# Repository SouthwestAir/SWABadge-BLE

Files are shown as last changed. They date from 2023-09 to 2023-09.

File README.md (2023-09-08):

# 📛 SWABadge

 






#### Custom BLE circuit, 3d printed case and button, and sample iOS code

## 💡 Concept

Creation of a wearable Bluetooth "badge" to receive urgent notifications, and respond immediately via a tap.

## 📜 Background

During our recent prototype testing in the lobby, we rolled out a feature enabling our Customer Service Agents (CSAs) to access tools via their mobile devices. We noticed that, especially during interactions with passengers, their iPads would accumulate numerous notifications.

We designed and built a Bluetooth button that vibrates for essential notifications, such as a passenger requiring assistance. With a simple press, CSAs can acknowledge and signal their response, effectively communicating, "Yes, I'm on it!" Leveraging our 3D printing capabilities and existing IoT expertise, we crafted a BLE circuit for this solution.

Our four-step build process was:

1. Build the BLE circuit
2. Integrate into the [chat code](https://github.com/SouthwestAir/SWAChat)
3. 3d print a case
4. Assemble and test!

### Integration into the chat code

We used the chat code from our previous open source project [`SWAChat`](https://github.com/SouthwestAir/SWAChat):

- [https://github.com/SouthwestAir/SWAChat](https://github.com/SouthwestAir/SWAChat)

After following the instructions (setting up and connecting to a Firebase instance) we will have a basis for adding our Bluetooth connectivity.

The first thing we need to do is modify the Info.plist to ask permission to use Bluetooth.

You can do this one of two ways:

a) In your Info.plist, add the row for "Privacy - Bluetooth Always Usage Description", and add a string that is something like "This app requires the use of Bluetooth to connect to our cool comm badge."

b) If you prefer to modify the plist via the "Open as source code" method, add this inside the parent `<dict></dict>` fields:

```
	<key>NSBluetoothAlwaysUsageDescription</key>
	<string>This app requires the use of Bluetooth to connect to our cool comm badge.</string>
```

Then you can copy or add a new file "NewToothManager.swift" found in this repository (in the `02-Chat-code` folder). That file connects and manages the comm device.

(This was built with the assumption that only one comm device will be used at a time, to make this simpler to implement. There are only two basic features for this device, although that could be enhanced as well.)

To integrate this feature into a ViewController, there are two features to implement.

The first is to notify a user when something requires their attention. The badge will vibrate when this message is successfully sent:

```
  // BLE Message sent to SWABadge device if available
  NewToothManager.shared.sendBuzz(msg: "notify user")
```

*<span style="color:red">(If using the ChatDemo, this can be added to the `reloadCurrentChatMessages` method of the `ChatViewController-Messages.swift` file, within the `if channel == currentChatRoom` code block.</span>)*

The second feature is to accept a response from the wearer. We do this by subscribing to an in-app notification, via the NotificationCenter singleton:

```
  NotificationCenter.default.addObserver(
    self,
    selector: #selector(self.swaBadgeTapped(_:)),
    name: Notification.Name.swaBadgeTapped,
    object: nil
  )
```

And we will need to do something with that message, like the following:

```
  @objc func swaBadgeTapped(_ notification: Notification) {
    // do something when the badge button is tapped

  }
```

*<span style="color:red">(If using the ChatDemo, this can be added to the `ChatViewController-Form.swift` file. Add the notification in `setupForm()`, paste the `swaBadgeTapped` method in the file, and replace the `TODO` with something like `sendMessage(self, message: "On it! (sent via SWABadge)")`.</span>)*

Then build and test, to make sure this feature is working with the circuit.

## 🚀 Future ideas

We had a number of enhancements that we've come up with, using this badge as a base. For example, we were thinking about adding a speaker and microphone to allow the wearer to hear a message (i.e. "help needed at gate C15", respond with their voice, and then use speech-to-text on their phone to submit it as a chat message). This would be complicated by having to send audio via a bytestream through Bluetooth.

## 💻 Contributors

The following members of Technology Innovation contributed to this project:

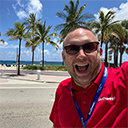
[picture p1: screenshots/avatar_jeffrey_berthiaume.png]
Jeffrey Berthiaume
|  |
| :---: | 
| Jeffrey Berthiaume  |
|  |
|  |
|  |

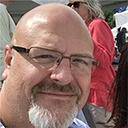
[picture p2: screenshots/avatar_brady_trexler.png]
Brady Trexler
|  |
| :---: | 
| E. Brady Trexler, PhD  |
|  |

## 📖 Citations

Reference to cite if needed:

```
@software {
	title = {SWA Badge},
	author = {Technology Innovation},
	affiliation = {Southwest Airlines},
	url = {https://github.com/SouthwestAir/SWABadge},
	month = {09},
	year = {2023},
	license: {BSD-3-Clause}
	version: {1.0}
}

```

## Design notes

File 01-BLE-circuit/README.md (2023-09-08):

# BLE Circuit

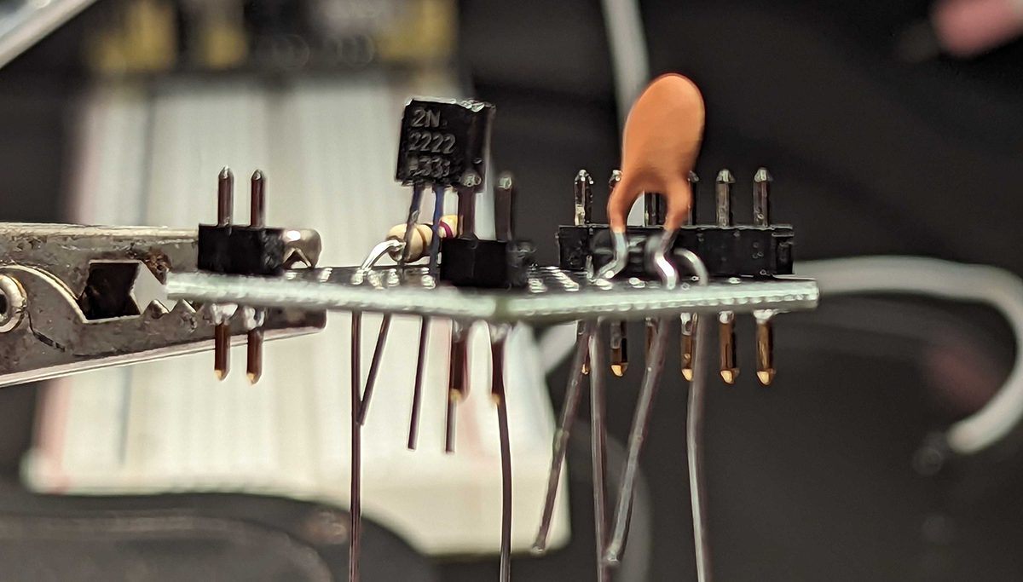
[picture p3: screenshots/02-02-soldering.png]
Soldering parts


The following parts were used to make this circuit:

- [SEEED STUDIO XIAO ESP32C3 WIFI+B](https://www.digikey.com/en/products/detail/seeed-technology-co-ltd/113991054/16652880)
- [VIBRATION ERM MTR 10000 RPM 3V](https://www.digikey.com/en/products/detail/seeed-technology-co-ltd/316040004/5487673)
- [Xiaoyztan 100 Pcs White Light LED Bead Chips DC 3.0-3.2V 280mA 1W Emitting Diodes LED Emitters (White Light)](https://www.amazon.com/gp/product/B07DWR671V/ref=ppx_yo_dt_b_asin_title_o04_s00?ie=UTF8&psc=1)
- [BOJACK 1000 Pcs 25 Values Resistor Kit 1 Ohm-1M Ohm with 5% 1/4W Carbon Film Resistors Assortment](https://www.tindie.com/products/debinix/tiny-1x1-through-hole-prototype-board/)
- [BOJACK 1N4007 Rectifier Diode 1 A 1000 V DO-41 Axial 4007 1 amp 1000 Volt Electronic Silicon Diodes(Pack of 125 Pieces)](https://www.amazon.com/gp/product/B07Q6J9TNW/ref=ppx_yo_dt_b_asin_title_o00_s00?ie=UTF8&psc=1)
- [BOJACK 2N2222 NPN 60V 0.8A 0.5W 250MHZ Power General Purpose Transistors(Pack of 200 Pcs)](https://www.amazon.com/gp/product/B07T61M92G/ref=ppx_yo_dt_b_asin_title_o03_s01?ie=UTF8&psc=1)
- [BOJACK 10 Values 300 Pcs Ceramic Capacitor 0.1 0.15 0.22 0.33 0.47 0.68 1 2.2 4.7 10 uF Multilayer Monolithic Ceramic Capacitor Assortment Kit](https://www.amazon.com/BOJACK-Capacitor-Multilayer-Monolithic-Assortment/dp/B085RDTCCV?th=1)
- [QTETAK 200 Pcs 10 Value Micro Momentary Tactile Push Button Switch Tact Assortment Kit](https://www.amazon.com/gp/product/B07LCBLB8N/ref=ppx_yo_dt_b_asin_title_o09_s00?ie=UTF8&psc=1)
- [Tiny 1”x1” Through Hole Prototype Board -- originally from Amazon, but no longer available](https://www.tindie.com/products/debinix/tiny-1x1-through-hole-prototype-board/)

These are the main steps we followed to construct this circuit:

- Utilize only one side of the ESP32 pins for simplified soldering and assembly.
- Connect pin D7 to the LED, functioning as a digital output. When set to HIGH, the LED will turn on. The SEEED XIAO-ESP32-C3 is capable of supplying the required current for the LED directly from its digital output pins.
- Power the vibration motor using the 3.3-volt output from the ESP32. Control the motor's operation through pin D8, which also serves as a digital output.

For more details:

[Sourcing parts](sourcing_parts.md)

[Constructing the circuit](building_the_circuit.md)

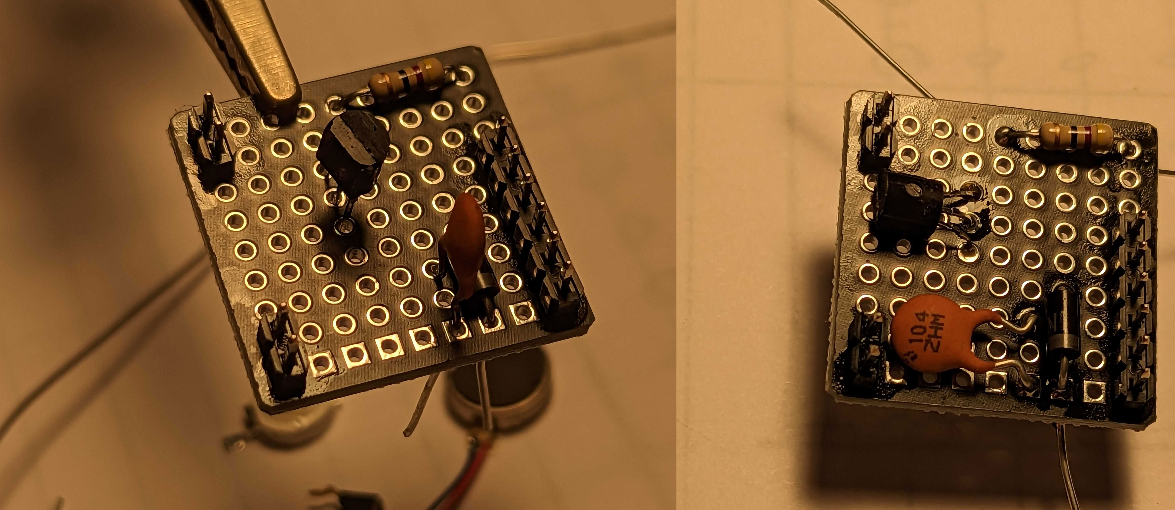
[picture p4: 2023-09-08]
01-BLE-circuit/circuit/circuit02.jpg

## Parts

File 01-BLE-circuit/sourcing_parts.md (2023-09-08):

SEEED STUDIO XIAO ESP32C3 WIFI+B  https://www.digikey.com/en/products/detail/seeed-technology-co-ltd/113991054/16652880

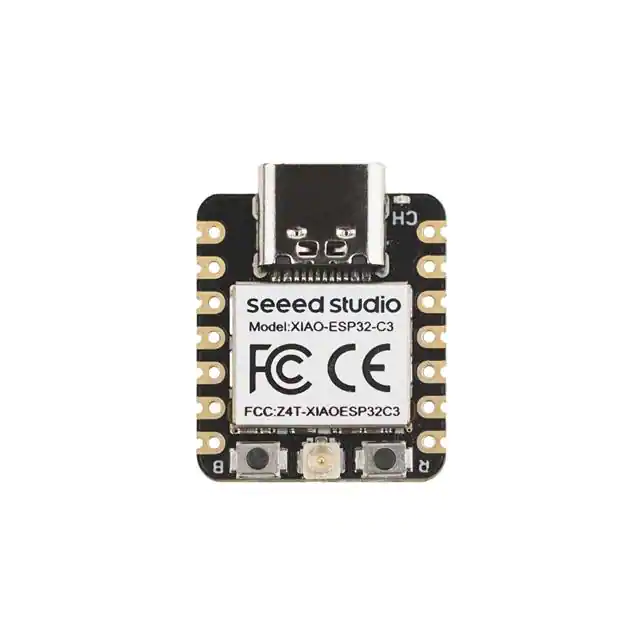
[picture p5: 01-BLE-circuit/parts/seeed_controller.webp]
SEEED STUDIO XIAO ESP32C3 WIFI+B


VIBRATION ERM MTR 10000 RPM 3V
https://www.digikey.com/en/products/detail/seeed-technology-co-ltd/316040004/5487673

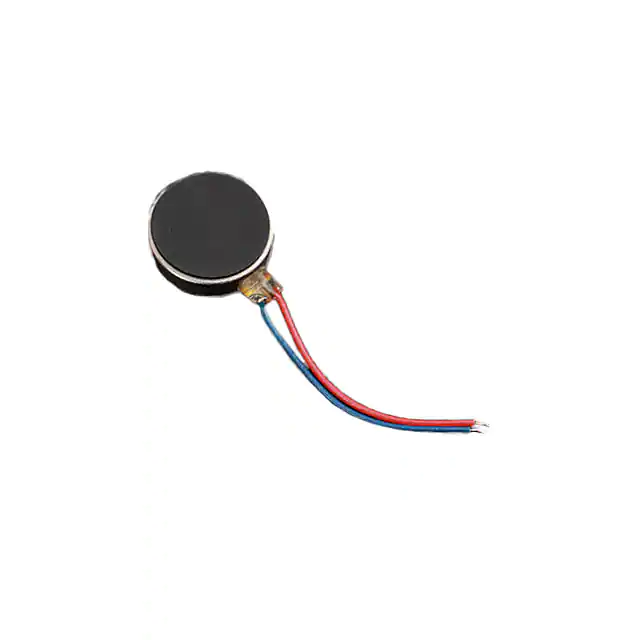
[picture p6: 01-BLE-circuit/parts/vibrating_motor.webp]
VIBRATION ERM MTR 10000 RPM 3V


Xiaoyztan 100 Pcs White Light LED Bead Chips DC 3.0-3.2V 280mA 1W Emitting Diodes LED Emitters (White Light)
https://www.amazon.com/gp/product/B07DWR671V/ref=ppx_yo_dt_b_asin_title_o04_s00?ie=UTF8&psc=1

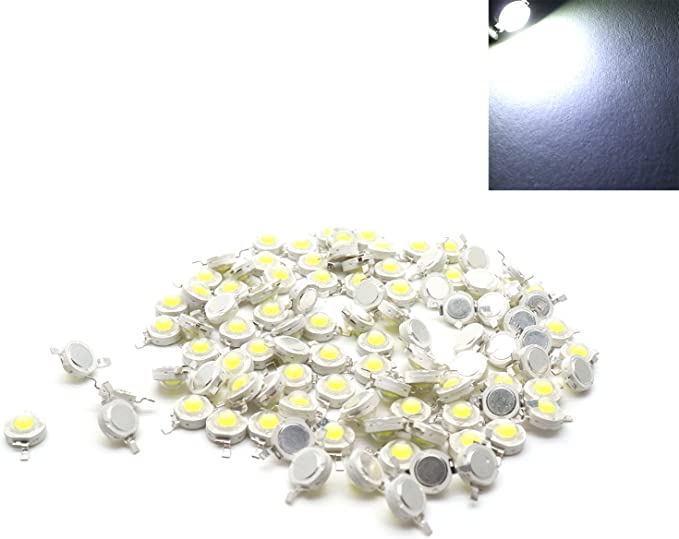
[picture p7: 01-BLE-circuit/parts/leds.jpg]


BOJACK 1000 Pcs 25 Values Resistor Kit 1 Ohm-1M Ohm with 5% 1/4W Carbon Film Resistors Assortment
https://www.tindie.com/products/debinix/tiny-1x1-through-hole-prototype-board/

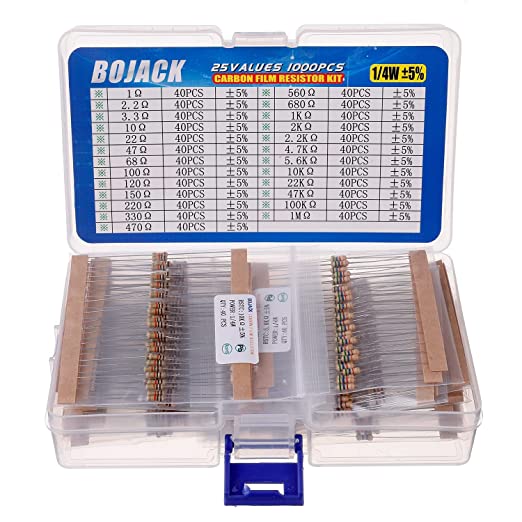
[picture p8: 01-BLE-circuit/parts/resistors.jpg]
BOJACK 1000 Pcs 25 Values Resistor Kit 1 Ohm-1M Ohm with 5% 1/4W Carbon Film Resistors Assortment


BOJACK 1N4007 Rectifier Diode 1 A 1000 V DO-41 Axial 4007 1 amp 1000 Volt Electronic Silicon Diodes(Pack of 125 Pieces)
https://www.amazon.com/gp/product/B07Q6J9TNW/ref=ppx_yo_dt_b_asin_title_o00_s00?ie=UTF8&psc=1

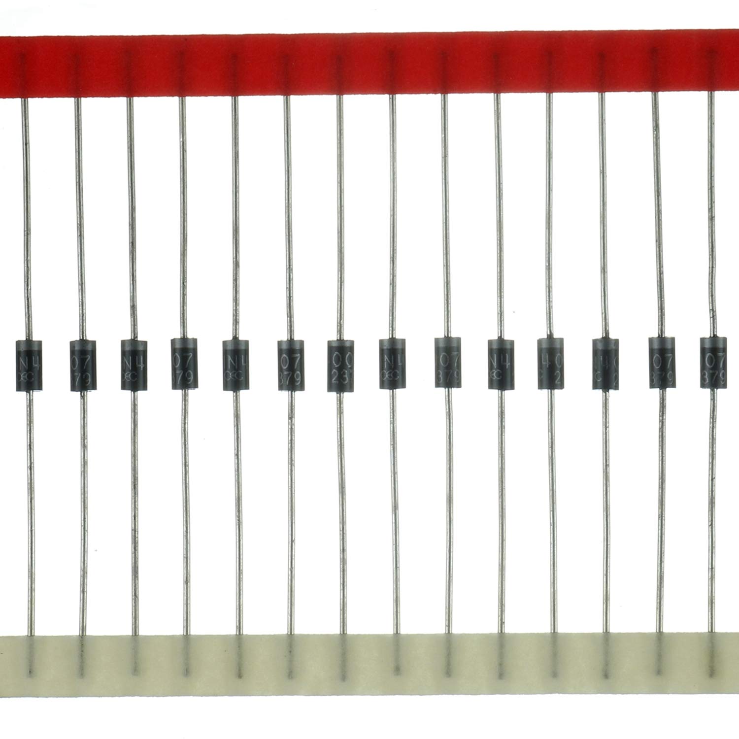
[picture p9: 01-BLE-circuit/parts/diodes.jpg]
BOJACK 1N4007 Rectifier Diode 1 A 1000 V DO-41 Axial 4007 1 amp 1000 Volt Electronic Silicon Diodes(Pack of 125 Pieces)


BOJACK 2N2222 NPN 60V 0.8A 0.5W 250MHZ Power General Purpose Transistors(Pack of 200 Pcs)
https://www.amazon.com/gp/product/B07T61M92G/ref=ppx_yo_dt_b_asin_title_o03_s01?ie=UTF8&psc=1

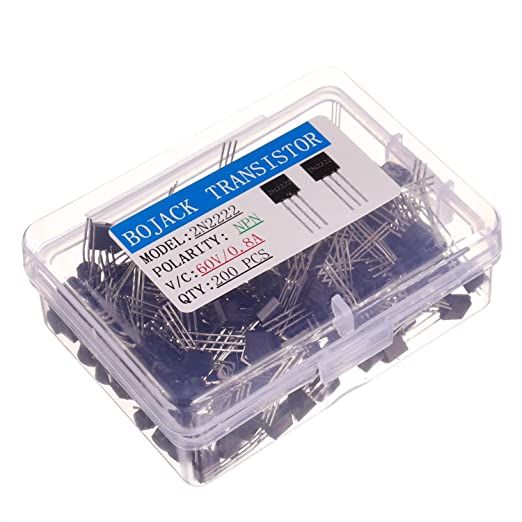
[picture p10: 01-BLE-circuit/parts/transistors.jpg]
BOJACK 2N2222 NPN 60V 0.8A 0.5W 250MHZ Power General Purpose Transistors(Pack of 200 Pcs)


BOJACK 10 Values 300 Pcs Ceramic Capacitor 0.1 0.15 0.22 0.33 0.47 0.68 1 2.2 4.7 10 uF Multilayer Monolithic Ceramic Capacitor Assortment Kit
https://www.amazon.com/BOJACK-Capacitor-Multilayer-Monolithic-Assortment/dp/B085RDTCCV?th=1

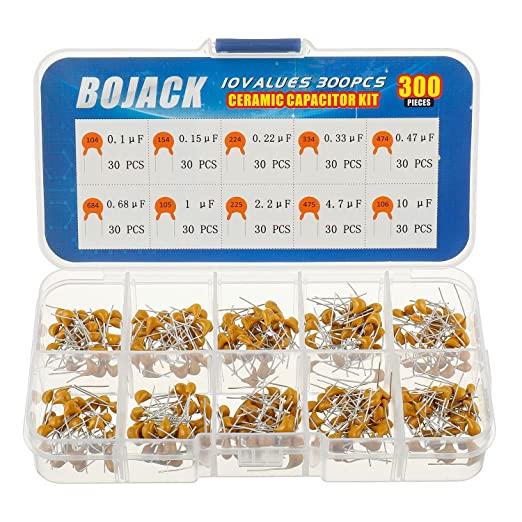
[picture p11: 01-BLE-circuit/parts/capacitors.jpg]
BOJACK 10 Values 300 Pcs Ceramic Capacitor 0.1 0.15 0.22 0.33 0.47 0.68 1 2.2 4.7 10 uF Multilayer Monolithic Ceramic Capacitor Assortment Kit


QTETAK 200 Pcs 10 Value Micro Momentary Tactile Push Button Switch Tact Assortment Kit
https://www.amazon.com/gp/product/B07LCBLB8N/ref=ppx_yo_dt_b_asin_title_o09_s00?ie=UTF8&psc=1

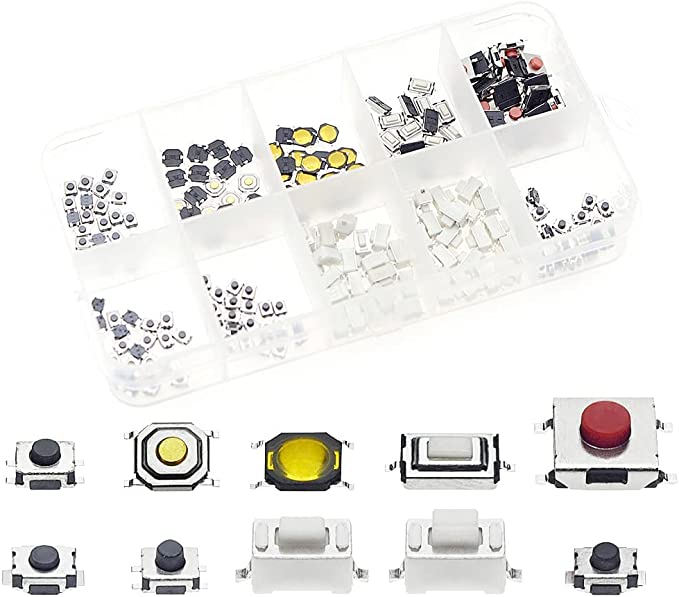
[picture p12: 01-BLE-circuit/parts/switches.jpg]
QTETAK 200 Pcs 10 Value Micro Momentary Tactile Push Button Switch Tact Assortment Kit


Tiny 1”x1” Through Hole Prototype Board -- originally from Amazon, but no longer available
https://www.tindie.com/products/debinix/tiny-1x1-through-hole-prototype-board/

Tiny 1”x1” Through Hole Prototype Board

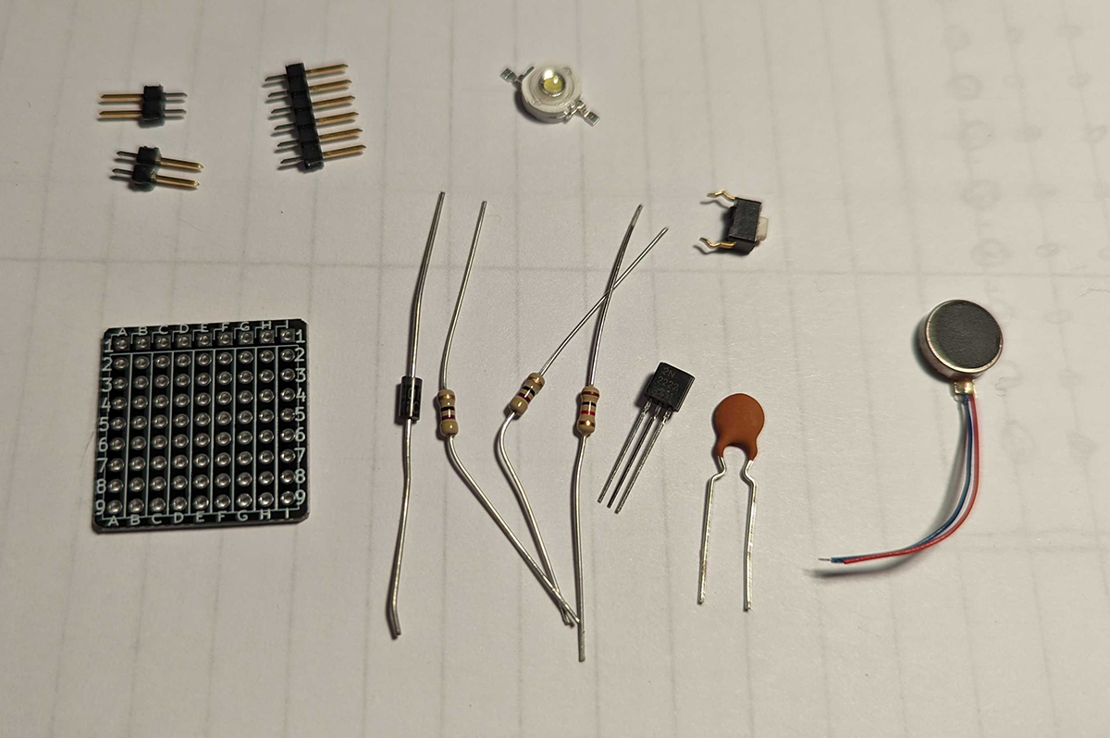
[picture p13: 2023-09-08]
screenshots/02-01-parts.png

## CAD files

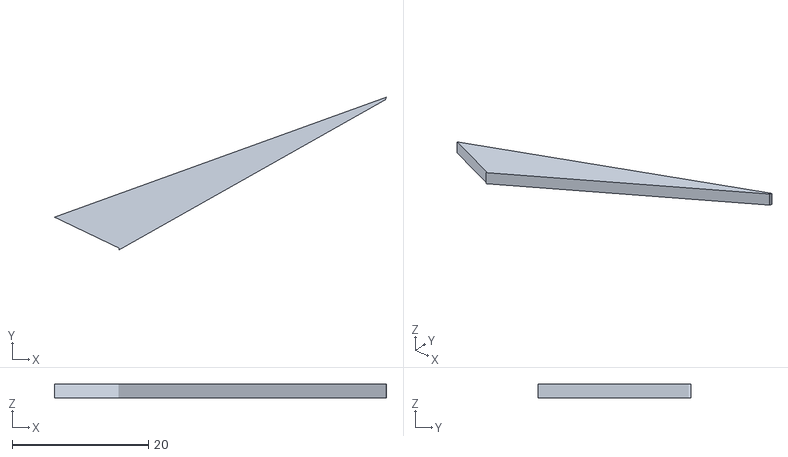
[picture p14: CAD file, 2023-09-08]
03-3d-printed-case/stl/SWAPlane-Yellow.stl
48.7 x 22.4 x 2.00

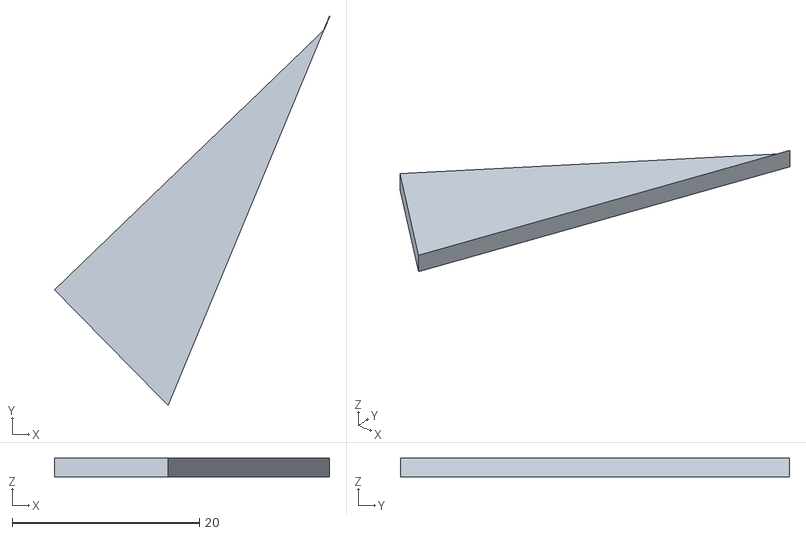
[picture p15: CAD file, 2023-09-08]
03-3d-printed-case/stl/SWAPlane-Blue.stl
29.4 x 41.5 x 2.00

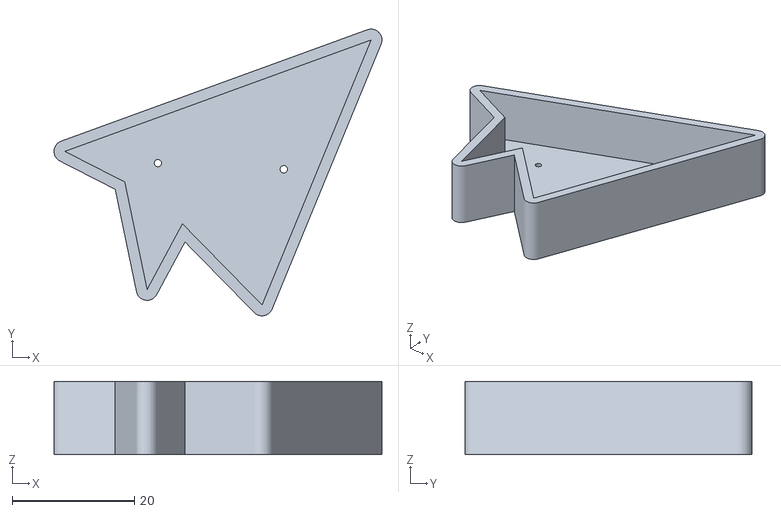
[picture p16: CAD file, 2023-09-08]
03-3d-printed-case/stl/SWAPlane-Box-Bottom-Black.stl
53.7 x 46.9 x 12.0

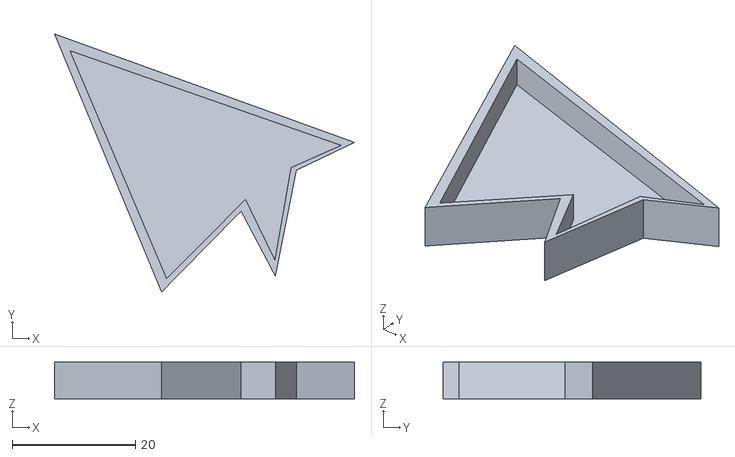
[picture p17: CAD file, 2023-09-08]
03-3d-printed-case/stl/SWAPlane-Button-Black.stl
48.7 x 41.9 x 6.00

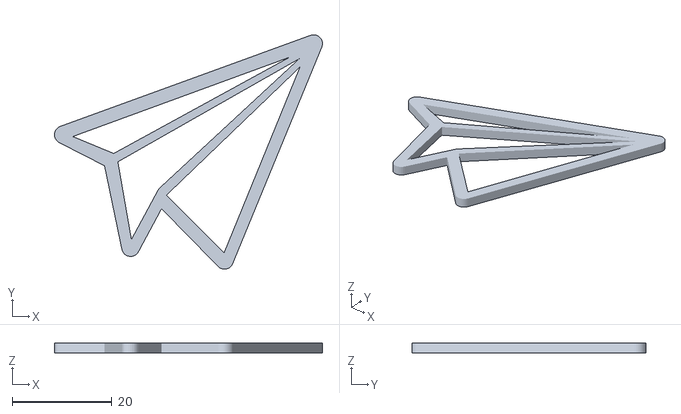
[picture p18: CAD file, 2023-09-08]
03-3d-printed-case/stl/SWAPlane-Box-Top-Silver.stl
53.7 x 46.9 x 2.00

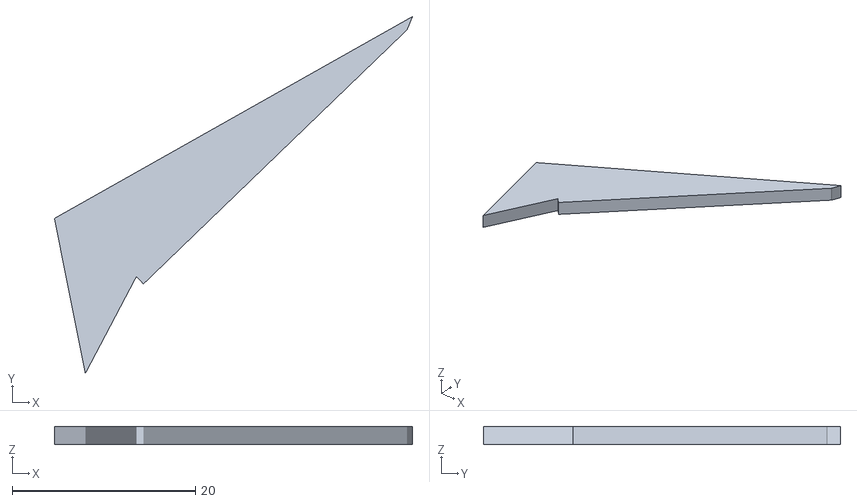
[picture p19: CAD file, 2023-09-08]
03-3d-printed-case/stl/SWAPlane-Red.stl
39.1 x 39.0 x 2.00

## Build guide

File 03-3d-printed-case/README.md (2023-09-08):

# 3D Printing a Case

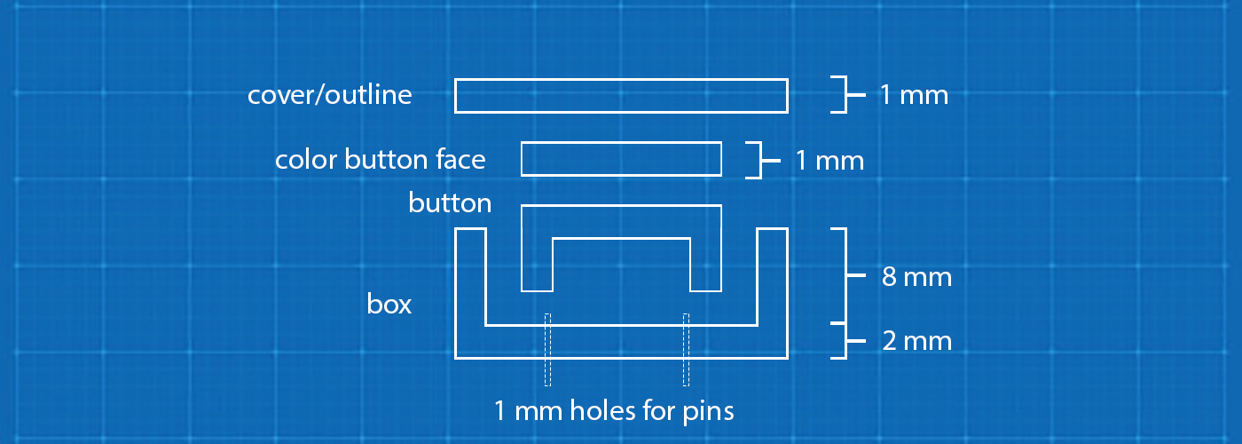
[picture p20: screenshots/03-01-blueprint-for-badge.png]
Initial blueprint


Equipment list:

- [Anycubic Vyper](https://www.anycubic.com/collections/3d-printers/products/anycubic-vyper) (3d printer)

Materials:

- [Black PLA](https://www.monoprice.com/product?p_id=10551) (for the box/base and the button)
- [Silver PLA](https://www.amazon.com/dp/B07QGV6D8P) (for the top/outline of the box)
- [Red PLA](https://www.monoprice.com/product?p_id=36277) (for the top of the button)
- [Yellow PLA](https://www.amazon.com/dp/B0BCCZK7W1 ) (for the top of the button)
- [Blue PLA](https://www.amazon.com/dp/B0BCDT5BNV) (for the top of the button)
- [Tie tack and butterfly clutch](https://www.amazon.com/dp/B072B9XGZ4) (to make into pin for clothing)
- [Gorilla Clear Grip glue](https://www.gorillatough.com/product/gorilla-clear-grip/) (for gluing the color pieces to the top of the button)

Software used:

- [Sketch](https://www.sketch.com/) (vector file editor)
- [TinkerCad](https://www.tinkercad.com/) (for creating the 3d shapes)
- [IdeaMaker](https://www.raise3d.com/ideamaker/) (for slicing the 3d files for printing)

Your process will likely be different, but here is what we did to build our badge prototype:

We started by importing the basic shape that we wanted to use in Sketch. We then created different shapes to represent the bottom of the badge, the top of the badge, and the inner button. There needs to be a small amount of space around the button, or it will fit too closely within the box and not be moveable.

Then we exported the layers as svg files (vector, so they would not lose fidelity). The vector files were created around 50x50 pixels (because TinkerCad imports these at 50mm x 50mm which is our target size).

In TinkerCad, we imported each svg file. For the most part, we tried to have each layer be 2 mm high, and we made the "box" part of the 12 mm high, and the "button" part about 6 mm. We printed a layer of colored panels that were glued to the top of the button-base.

To "hollow out" the box and the button, we raised the height as mentioned above. Then we imported the appropriate "hollow" file. In TinkerCad, changing the color from `Solid` to `Hole` makes it semi-transparent. We'd move the hollow piece up 2 mm (to allow for the bottom of the container), and then we'd select both objects and group them.

With the box piece, we also dragged a hollow cylinder from the Basic Shapes list, positioned it, and made it 1mm x 1mm. We used this to drill a hole through the base, and then we copied and positioned another one. This gave us some holes that could be used to push the pin (tie tack) through the base.

Then we pulled the files into IdeaMaker (one at a time) and sliced them. Those sliced files are in the `gcode` folder - but they are specific to the printer we are using, so we recommend slicing your own files. No supports are needed, and we had 10% infill turned on, although that really doesn't make a difference for these files. 

Also (personal preference) we rotated the color files to be upside down (as well as the other files with a flat face) because the heated plate on our printer has a nice pattern that melts into the face, so it looks a little less 3d printed.

For effiency, we also printed nine at a time.

### Final Assembly and Testing

We copied the gcode files to an SD card and started printing the pieces. We used different color filaments to print each piece.

There's a bit of a learning curve when printing these. The button base was misaligned, and ended up having a hole in it and needed to be re-printed. Each piece took between 30-45 minutes to print.

Pushing the pins through the base (even with the pre-printed holes) was difficult until we figured out to use needle-nosed pliers and gently but firmly push them through.

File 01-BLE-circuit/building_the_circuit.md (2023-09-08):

***
# Using the SEEED XIAO-ESP32-C3 as a Two-Way BLE communicator and circuit controller
***  

We used the pins from one side only of the ESP32 to make soldering and assembly easy.  

Pin D7 (as a digital output) turns the LED on when HIGH.  The SEEED XIAO-ESP32-C3 provides enough current for the LED directly from its digital output pins.

The 3.3 volt output from the ESP32 powers the vibration motor.  Operation of the motor is controlled by pin D8 (as a digital output).  

The 2N2222 transistor acts as a switch that allows current to flow from the 3.3 volt pin to ground when D8 is HIGH.  The 3.3 volt pin can source more current than the D8 pin can, which is why we used a switched circuit.  

The 1N4007 diode and 0.1 &mu;F capacitor protect the XIAO-ESP32-C3 from reverse currents that can arise when the motor shuts off.

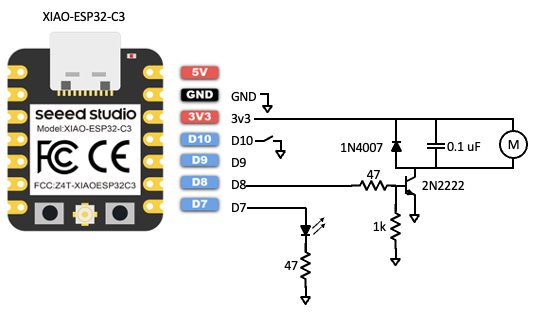
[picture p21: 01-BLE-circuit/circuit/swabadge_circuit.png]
Circuit diagram


&nbsp; 
***
### The goal of this circuit design was to create an assembly with the lowest profile possible.  
***  
&nbsp; 

The ESP32 is inverted for soldering.  The shape of the ESP32's solder pads allows for connection without wires.  
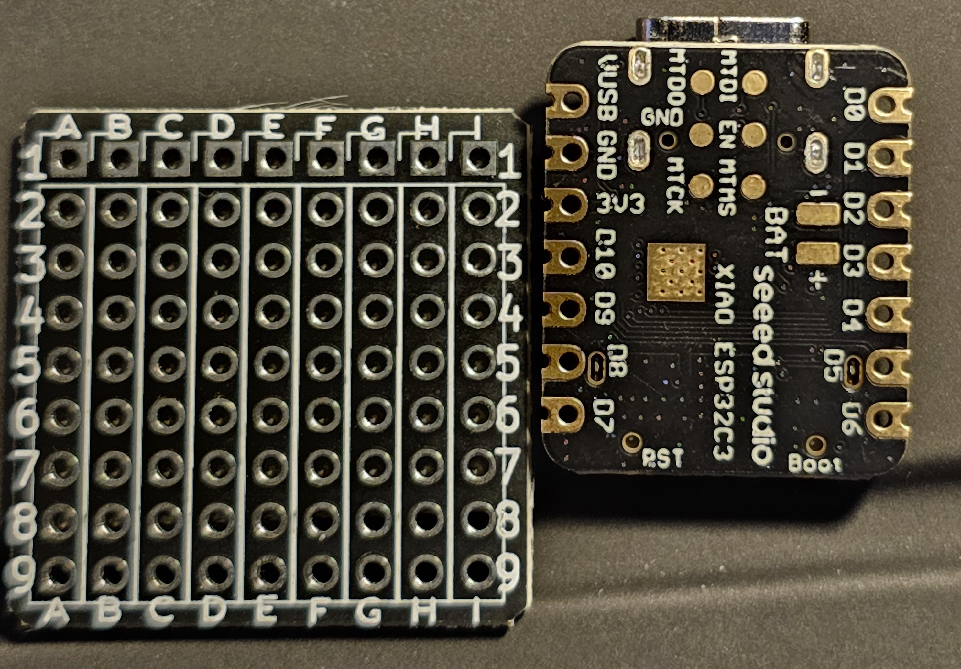
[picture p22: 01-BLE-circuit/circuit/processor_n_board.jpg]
Board and Processor Placement


Proper clamping and use of flux when soldering permits solid, low-profile connections between the two.
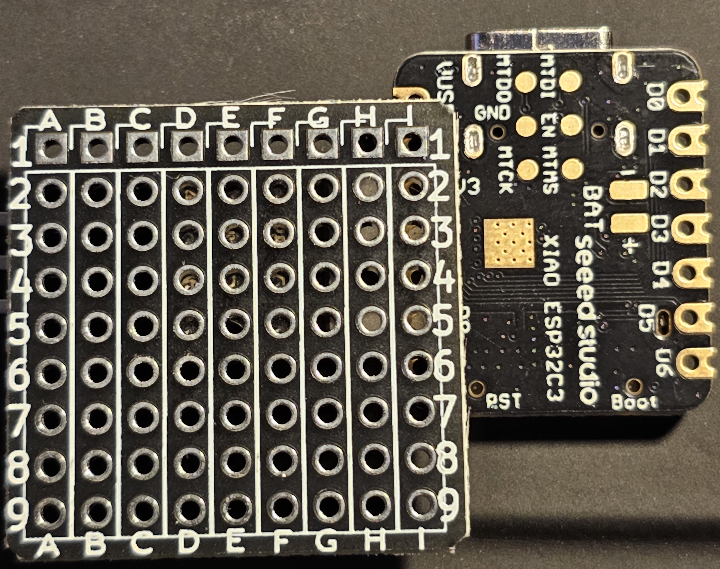
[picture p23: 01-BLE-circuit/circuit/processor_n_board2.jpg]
Board and Processor Placement 2


After soldering, the connections between the prototype board and the  SEEED XIAO-ESP32-C3 will look like this:

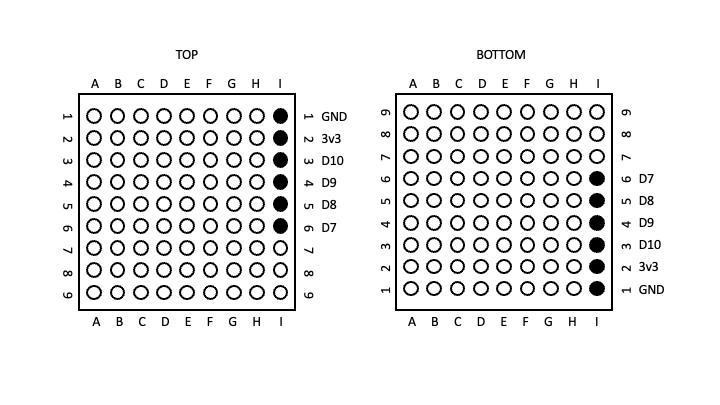
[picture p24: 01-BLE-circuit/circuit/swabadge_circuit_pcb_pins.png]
Pinout diagram


Placement and connection of the components (after many iterations) ended up with the bodies of some parts on the bottom and some on the top.  Slightly transparent parts from the opposite side are depicted to limit accidental soldering where a part's body needs to be.

Column A in this figure is used as a ground plane.  The green wires from GND to I-9 and then to A-9 connect one end of the switch, 1K&Omega; resistor, and the 2N2222 transistor emitter pin (pin 1) to ground.

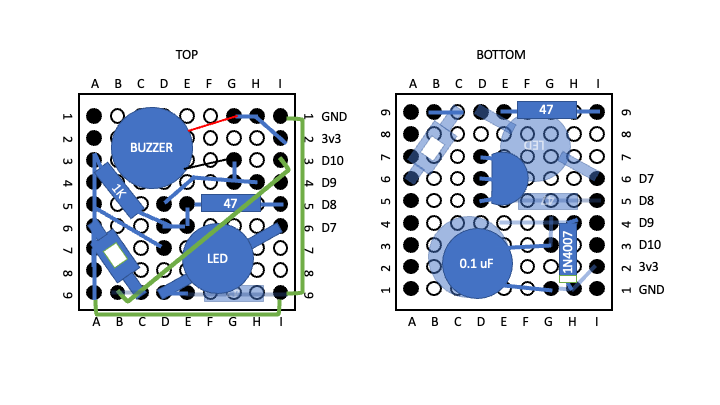
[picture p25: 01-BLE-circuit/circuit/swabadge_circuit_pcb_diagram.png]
Connection diagram


The orientations of the diode and transistor are key.  The diode has a silver ring around the side that should be connected to the 3.3 V pin.  The transistor's emitter pin should connect to ground.
 
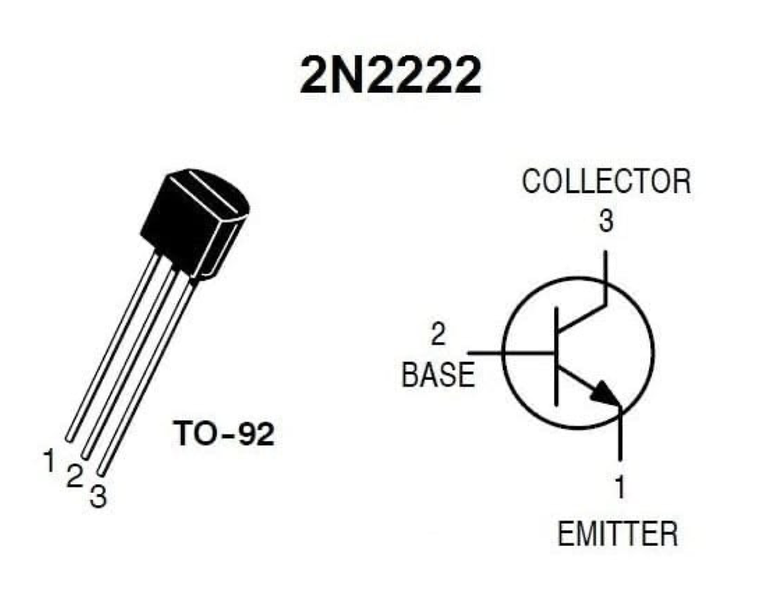
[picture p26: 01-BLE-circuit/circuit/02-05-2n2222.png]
2n2222 Diagram


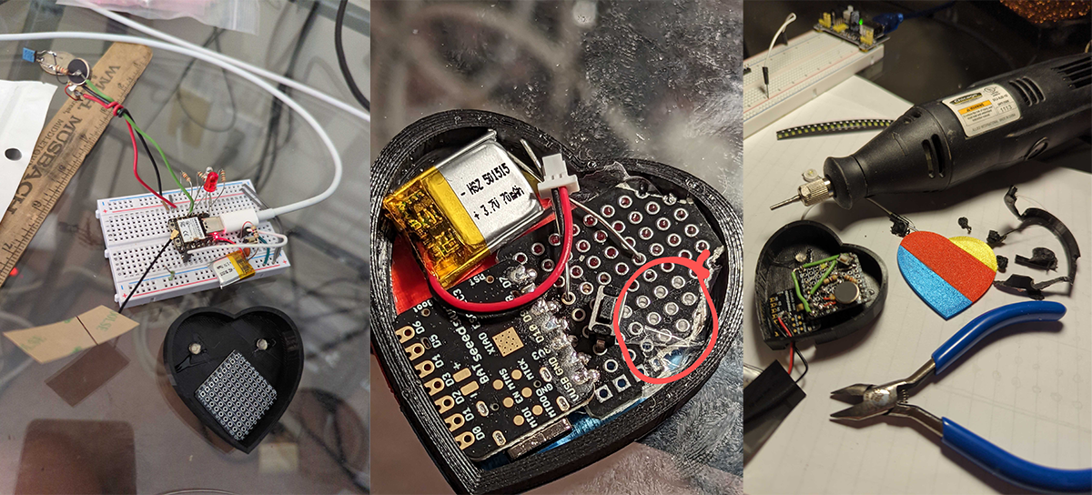
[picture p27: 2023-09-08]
screenshots/02-03-assembly.png
